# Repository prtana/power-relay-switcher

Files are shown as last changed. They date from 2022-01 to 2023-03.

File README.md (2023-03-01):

# Power Relay Switcher

**Power Relay Switcher** is an electronic device consisting of **4 relays**, each of which is capable of switching loads of up to **20 A**, **240 V AC** or **28 V DC**. Each of the four relays can be **manually** closed/opened from the **front panel** or via **USB** using **SCPI** commands. 

The device was designed for the automation of running battery pack management unit learning cycles for batteries up to a capacity of 200 Ah. In that application it is to be used in conjunction with a power supply, an electronic load and a multimeter. These battery learning cycles require charging-resting-discharging-resting periods in excess of 24 hours which are cumbersome for an operator to manually manage having to connect and disconnect a power supply and an electronic load at the exact moments determined by the learning cycle.

Power Relay Switcher

## User's Guide

### Front Panel
On the front panel there is a main **ON-OFF** rocker switch and **two toggle switches: USB/Manual** and **Close/Open** together with **two status LEDs** per relay. 

Front Panel

#### USB/Manual Switch
The **USB/Manual** switch allows the operator to choose whether the relay ought to be operated via **USB** using **SCPI** commands or **manually**. 

- If the **USB/Manual** switch is at the **USB** position, the **Close/Open** switch is disabled. 
- If the **USB/Manual** switch is switched from **USB** to **Manual**, the relay will be set to the position determined by the **Close/Open** switch. 
- If the **USB/Manual** switch is switched from **Manual** to **USB**, the relay will remain in the position last set by the **Close/Open** switch until a new **SCPI** command is sent to close or open it.

#### Close/Open Switch
The **Close/Open** switch allows the operator to manually close and open the relay contacts if the **USB/Manual** switch is at the **Manual** position. 

#### Status LEDs
There are two status LEDs per relay which indicate whether the relay contacts are in the **Closed** or **Open** position. 

### Rear Panel
On the rear panel there are:
- **USB Type-B** socket for SCPI control
- **Terminal blocks** with plugs for connecting to the relays' **Normally Open** (NO) and **Common** (COM) pins
- **Cooling fan**
- **230 V AC** mains C14 socket

Rear Panel

### SCPI
The following SCPI commands are supported:

- `*IDN?\n`
- `ROUTe:CLOSe (<channel list>)\n`
- `ROUTe:CLOSe? (<channel list>)\n`
- `ROUTe:OPEN (<channel list>)\n`
- `ROUTe:OPEN? (<channel list>)\n`

`<channel list>` is a list of relay channels to be switched or queried. It can be a single channel, i.e `2`, a comma seperated list, i.e `2,4` or a range, i.e `1:3`.

#### \*IDN?\n
- Device identification query.
- Returns the vendor, model, serial number and firmware version in comma seperated format.
- Example `*IDN?\n` returns `Deeply Embedded,Power Relay Switcher,0,0\n`.

#### ROUTe:CLOSe (\<channel list\>)\n
- Closes the relays specified by the `<channel list\>`.
- The relay's **USB/Manual** switch has to be set to **USB** in order to switch it using SCPI.
- Returns nothing.
- Example to close relays one and four: `ROUT:CLOS (1,4)\n`

#### ROUTe:CLOSe? (\<channel list\>)\n
- Queries whether the relays specified by the `<channel list\>` are closed.
- Returns the status of queried relays in a comma seperated form, where 1 - closed, 0 - open.
- Example to query relays one to four: `ROUT:CLOS? (1:4)\n`; returns in case if relay one is closed and two to four are open: `1,0,0,0\n`.

#### ROUTe:OPEN (\<channel list\>)\n
- Opens the relays specified by the `<channel list\>`. 
- The relay's **USB/Manual** switch has to be set to **USB** in order to switch it using SCPI.
- Returns nothing.
- Example to open relays one to three: `ROUT:OPEN (1:3)\n`.

#### ROUTe:OPEN? (\<channel list\>)\n
- Queries whether the relays specified by the `<channel list\>` are open.
- Returns the status of queried relays in a comma seperated form, where 1 - open, 0 - closed.
- Example to query relays one to four: `ROUT:OPEN? (1:4)\n`; returns in case if relay one is closed and two to four are open: `0,1,1,1\n`.

#### Usage Example
- Determine the COM port in use.
- Use your preferred terminal program. In this case **PUTTY** is used, the COM port is `/dev/ttyACM1` and baudrate is selected `115200`. 

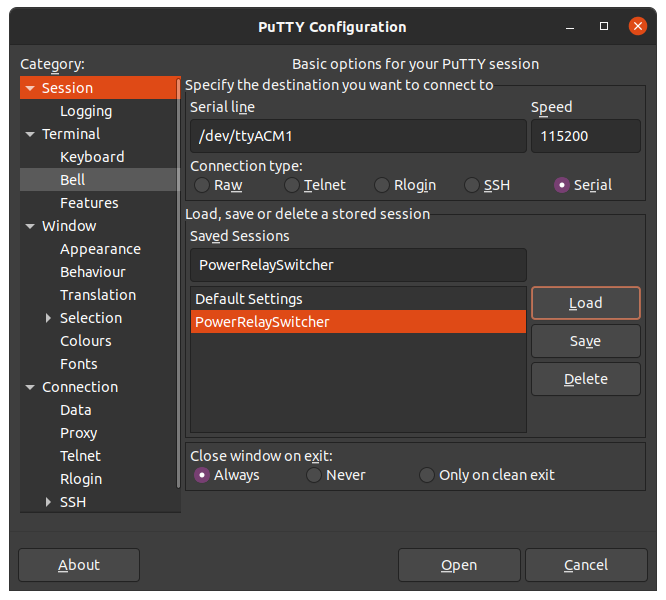
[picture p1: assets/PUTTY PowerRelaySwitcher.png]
PUTTY Configuration

- For PUTTY, make sure to select `Force on` for `Local echo` and `Local line editing` to see the typed text and to send the whole line at once rather than character by character.

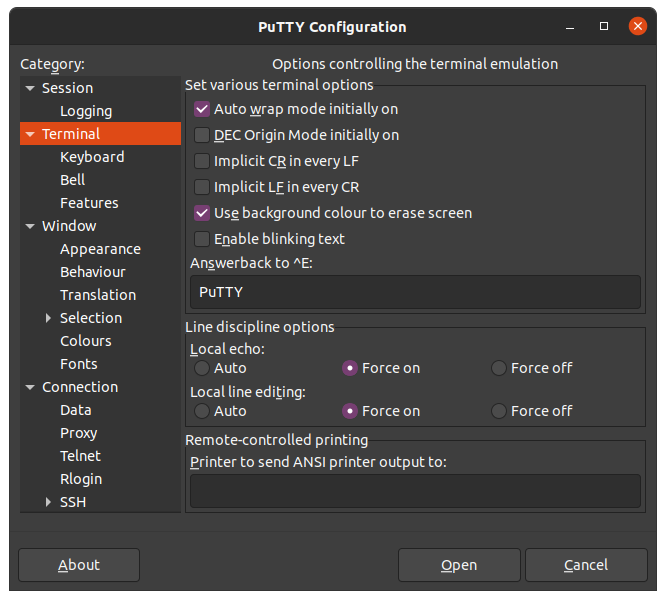
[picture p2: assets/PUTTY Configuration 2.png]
PUTTY Configuration


- Example comminucation is as follows. Note that a newline character `\n` can be entered in PUTTY by `Ctrl + J` and is displayed as `^J`.

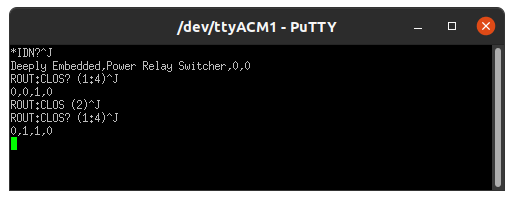
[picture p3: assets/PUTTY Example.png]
PUTTY Example Communication


## Project Overview

### Firmware
The C code for the STM32L062K8Tx microcontroller is in the [/firmware/power-relay-switcher](https://github.com/prtana/power-relay-switcher/tree/main/firmware/power-relay-switcher) directory.

### Hardware
There are relevant files in the [/hardware](https://github.com/prtana/power-relay-switcher/tree/main/hardware) directory for the three PCBs: the main PCB and the aluminium front and back panels.

#### Main PCB
For the main PCB the following resources are available:
- [3D step model](https://github.com/prtana/power-relay-switcher/tree/main/hardware/PRS_relay_board/3D)
- [Bill of materials](https://github.com/prtana/power-relay-switcher/tree/main/hardware/PRS_relay_board/BOM)
- [KiCad project](https://github.com/prtana/power-relay-switcher/tree/main/hardware/PRS_relay_board/KiCad)
- [Gerber files](https://github.com/prtana/power-relay-switcher/tree/main/hardware/PRS_relay_board/Gerbers)
- [PDF schematic](https://github.com/prtana/power-relay-switcher/blob/main/hardware/PRS_relay_board/PRS_relay_board.pdf)

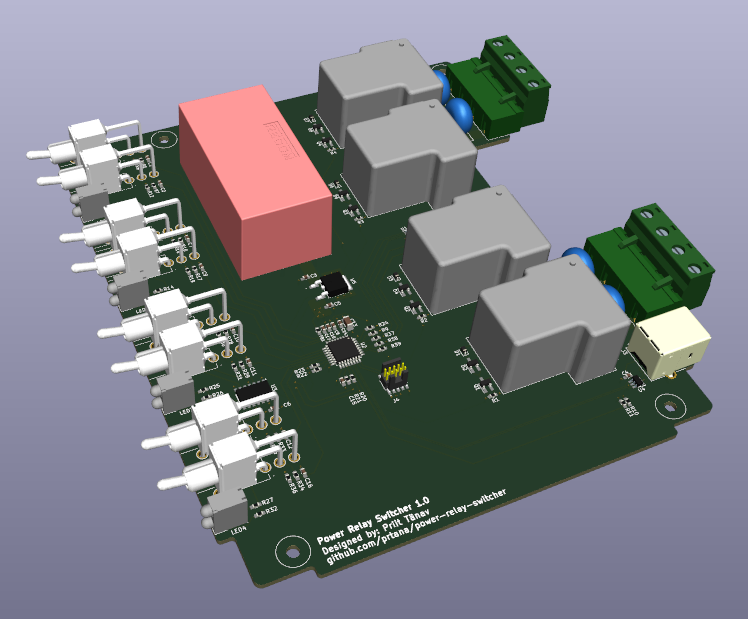
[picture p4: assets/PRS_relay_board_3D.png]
Relay Board


#### Front Panel
For the aluminium front panel the following resources are available:
- [3D step model](https://github.com/prtana/power-relay-switcher/tree/main/hardware/PRS_front_panel/3D)
- [KiCad project](https://github.com/prtana/power-relay-switcher/tree/main/hardware/PRS_front_panel/KiCad)
- [Gerber files](https://github.com/prtana/power-relay-switcher/tree/main/hardware/PRS_front_panel/Gerbers)

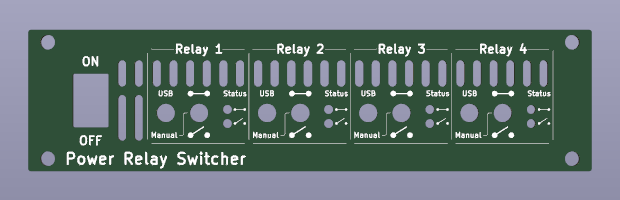
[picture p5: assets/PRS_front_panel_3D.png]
Front Panel


#### Rear Panel
For the aluminium rear panel the following resources are available:
- [3D step model](https://github.com/prtana/power-relay-switcher/tree/main/hardware/PRS_rear_panel/3D)
- [KiCad project](https://github.com/prtana/power-relay-switcher/tree/main/hardware/PRS_rear_panel/KiCad)
- [Gerber files](https://github.com/prtana/power-relay-switcher/tree/main/hardware/PRS_rear_panel/Gerbers)

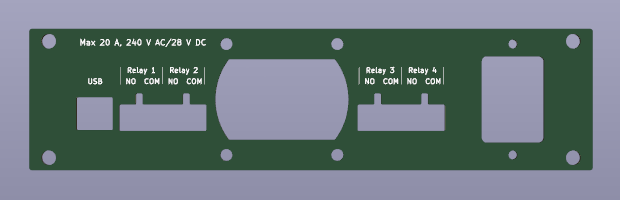
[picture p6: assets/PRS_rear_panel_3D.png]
Rear Panel


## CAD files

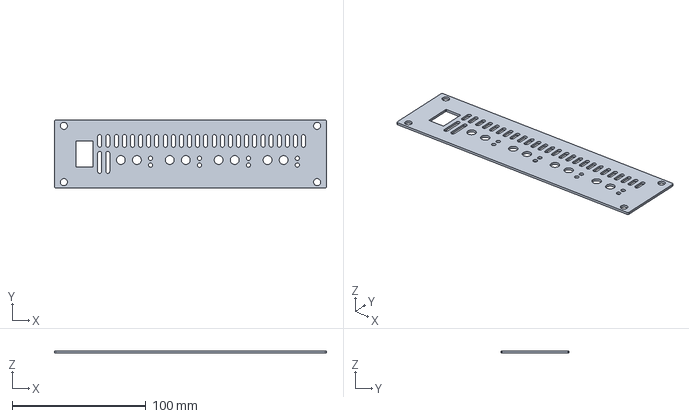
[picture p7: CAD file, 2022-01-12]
hardware/PRS_front_panel/3D/PRS_front_panel.step
203.0 x 51.0 x 1.60 mm

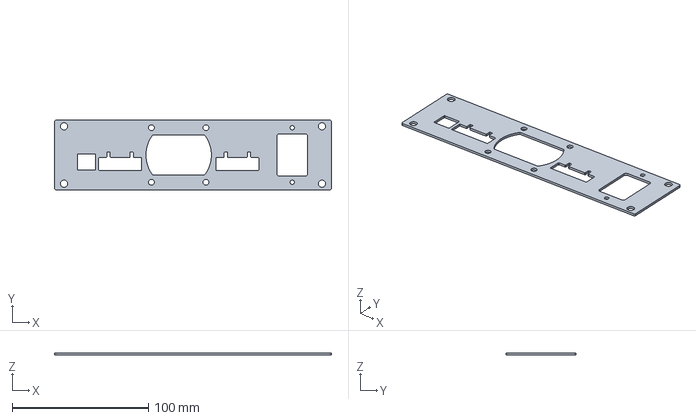
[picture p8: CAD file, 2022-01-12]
hardware/PRS_rear_panel/3D/PRS_rear_panel.step
203.0 x 51.0 x 1.60 mm

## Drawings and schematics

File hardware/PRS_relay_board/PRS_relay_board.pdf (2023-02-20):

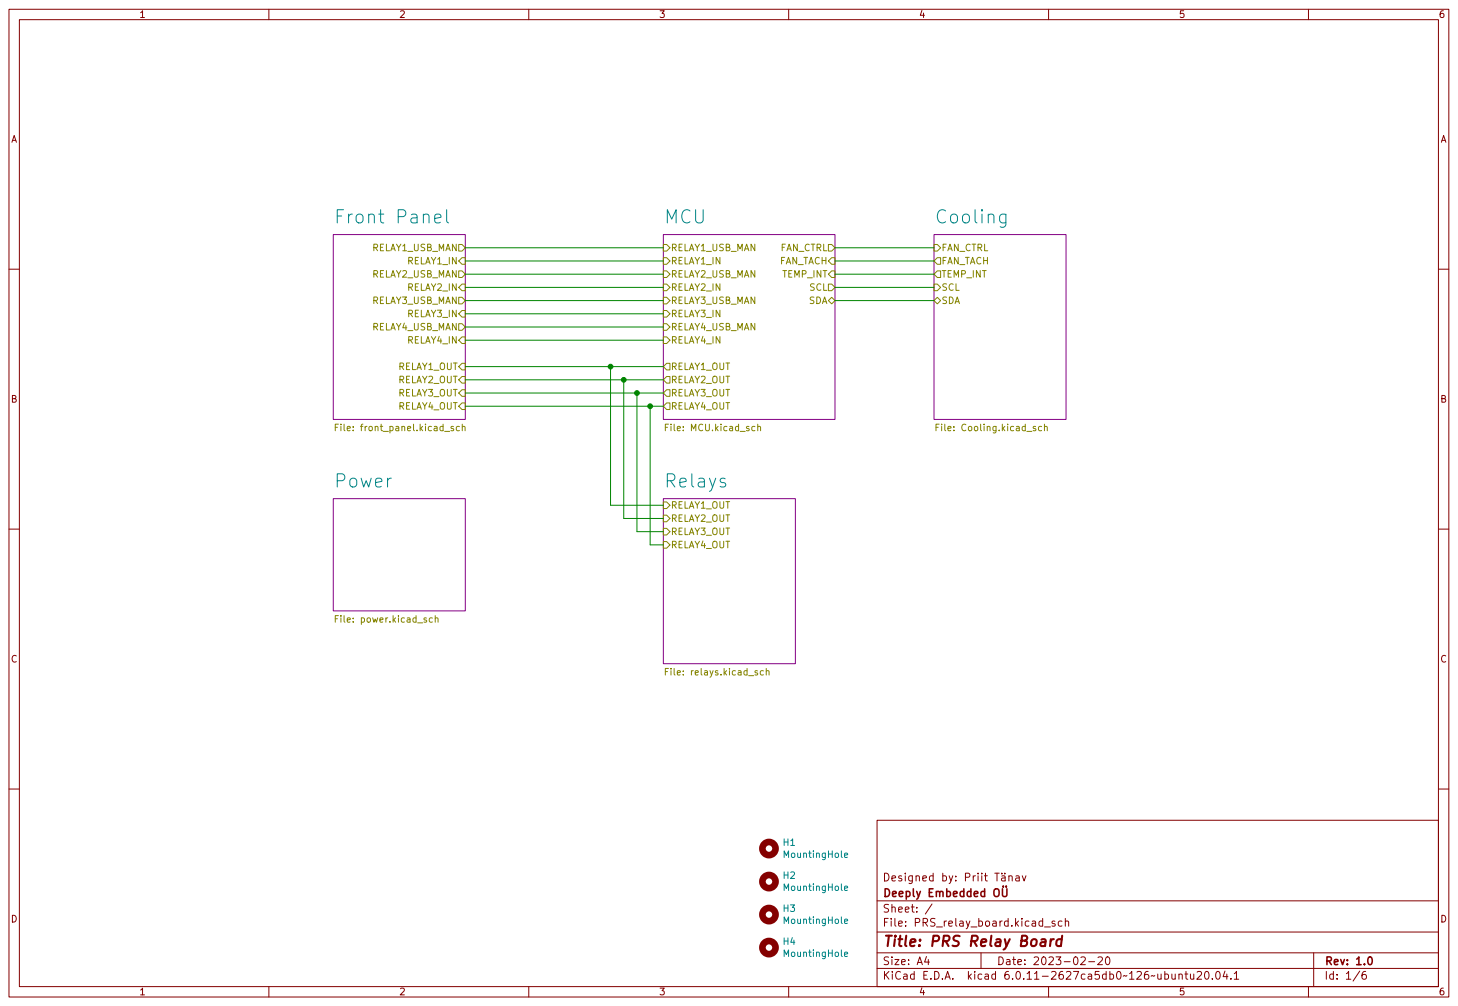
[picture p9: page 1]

File: power.kicad_sch RELAY1_USB_MAN
File: Cooling.kicad_sch H4 MountingHole H3 MountingHole H2 MountingHole H1 MountingHole

Id: 1/6 Title: PRS Relay Board

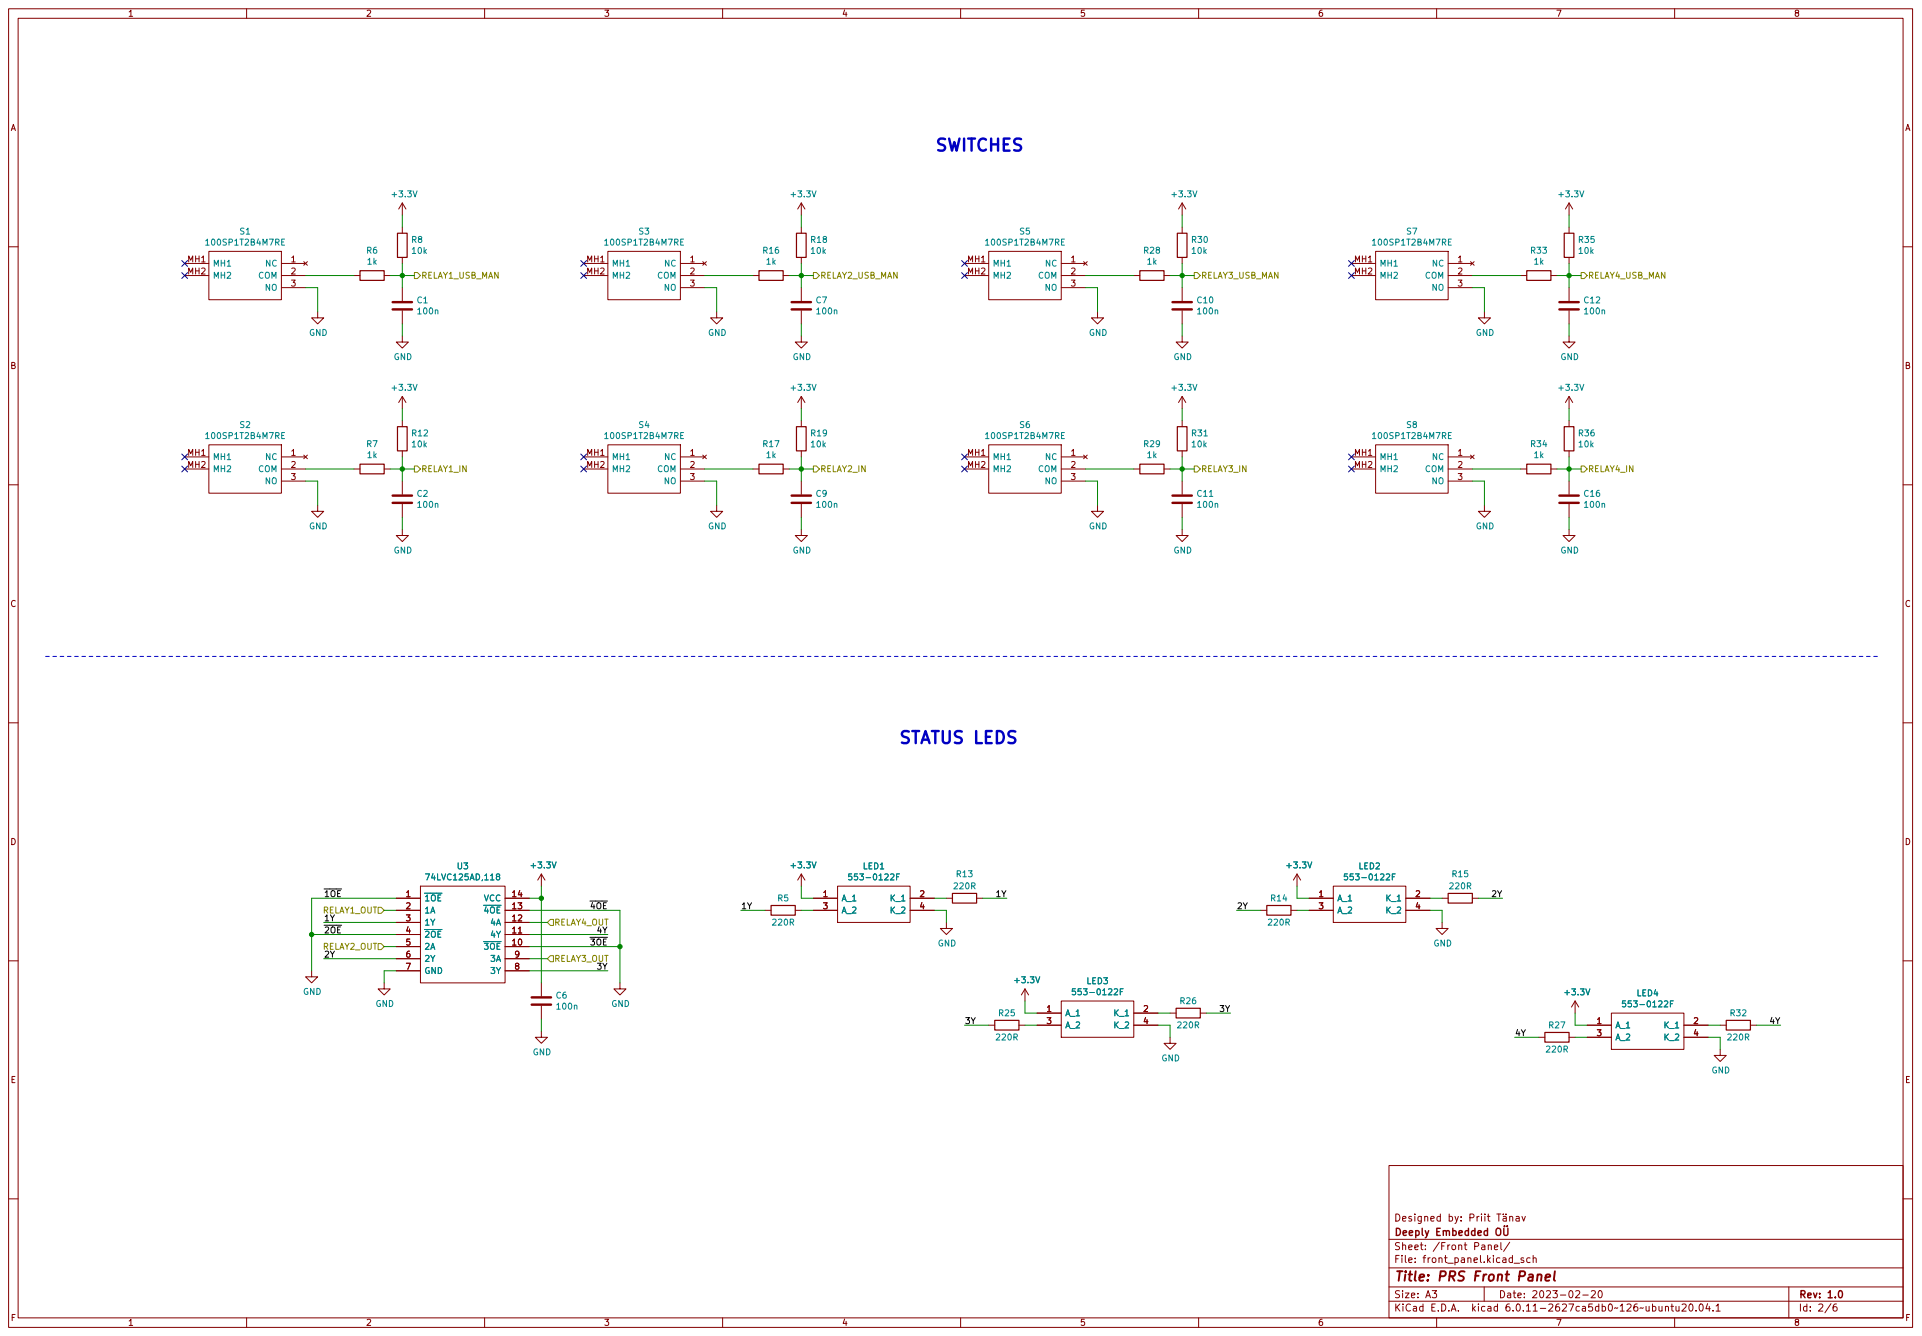
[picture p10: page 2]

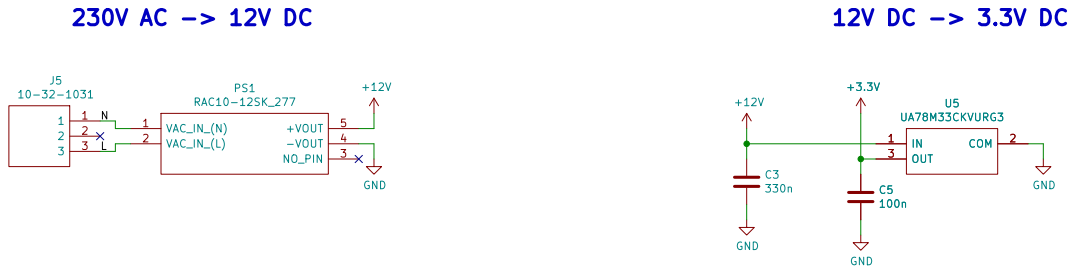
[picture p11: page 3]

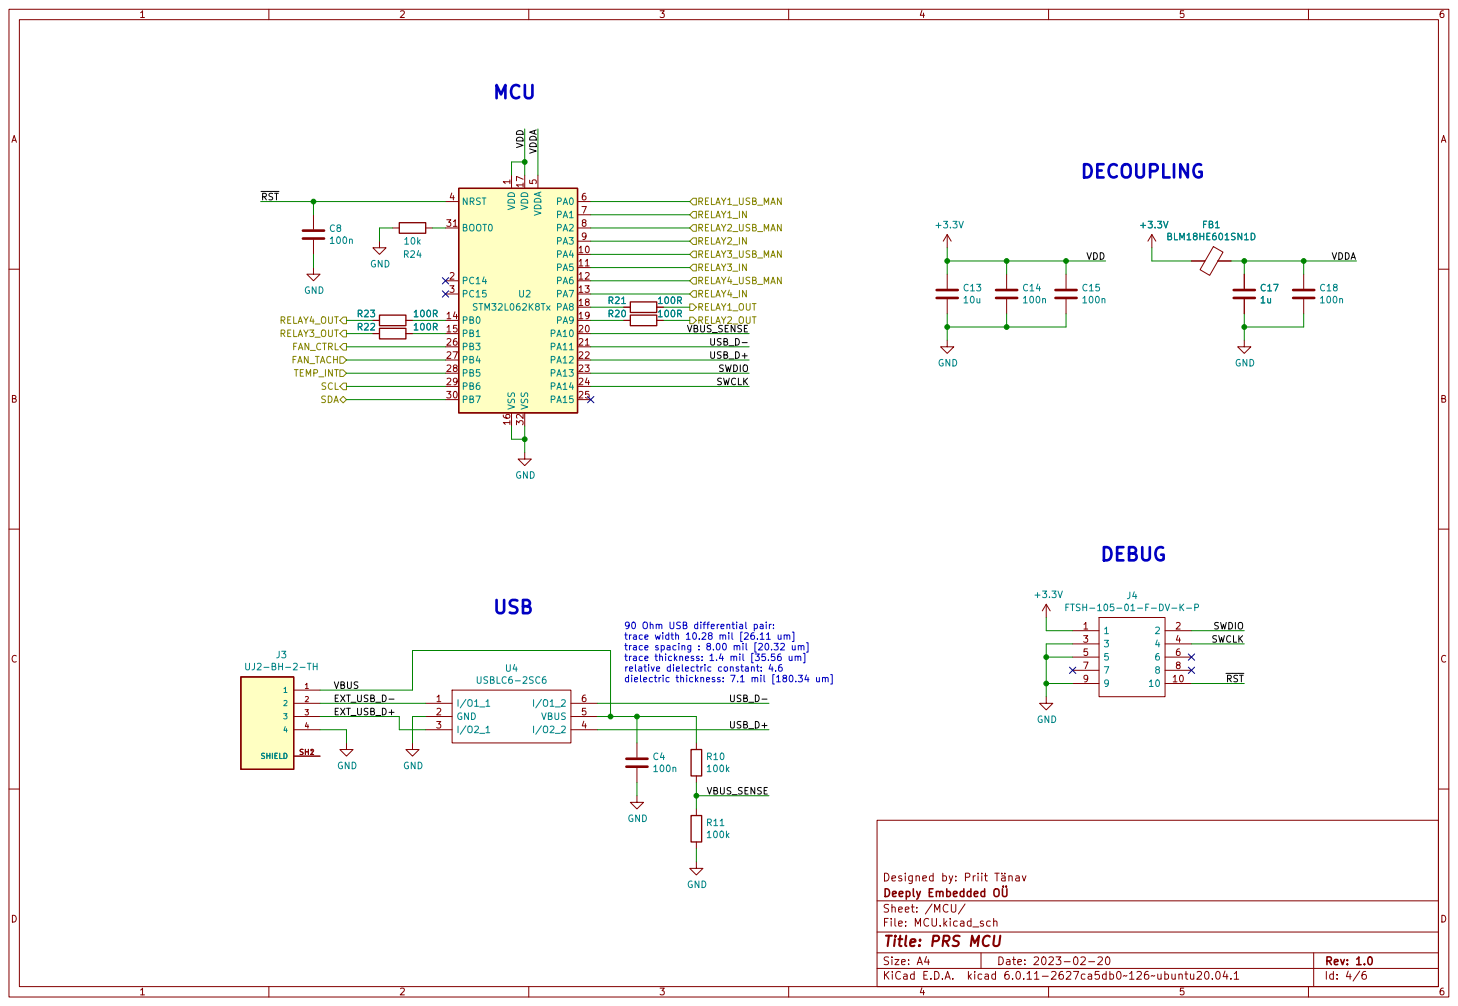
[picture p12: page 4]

Id: 4/6 Title: PRS MCU

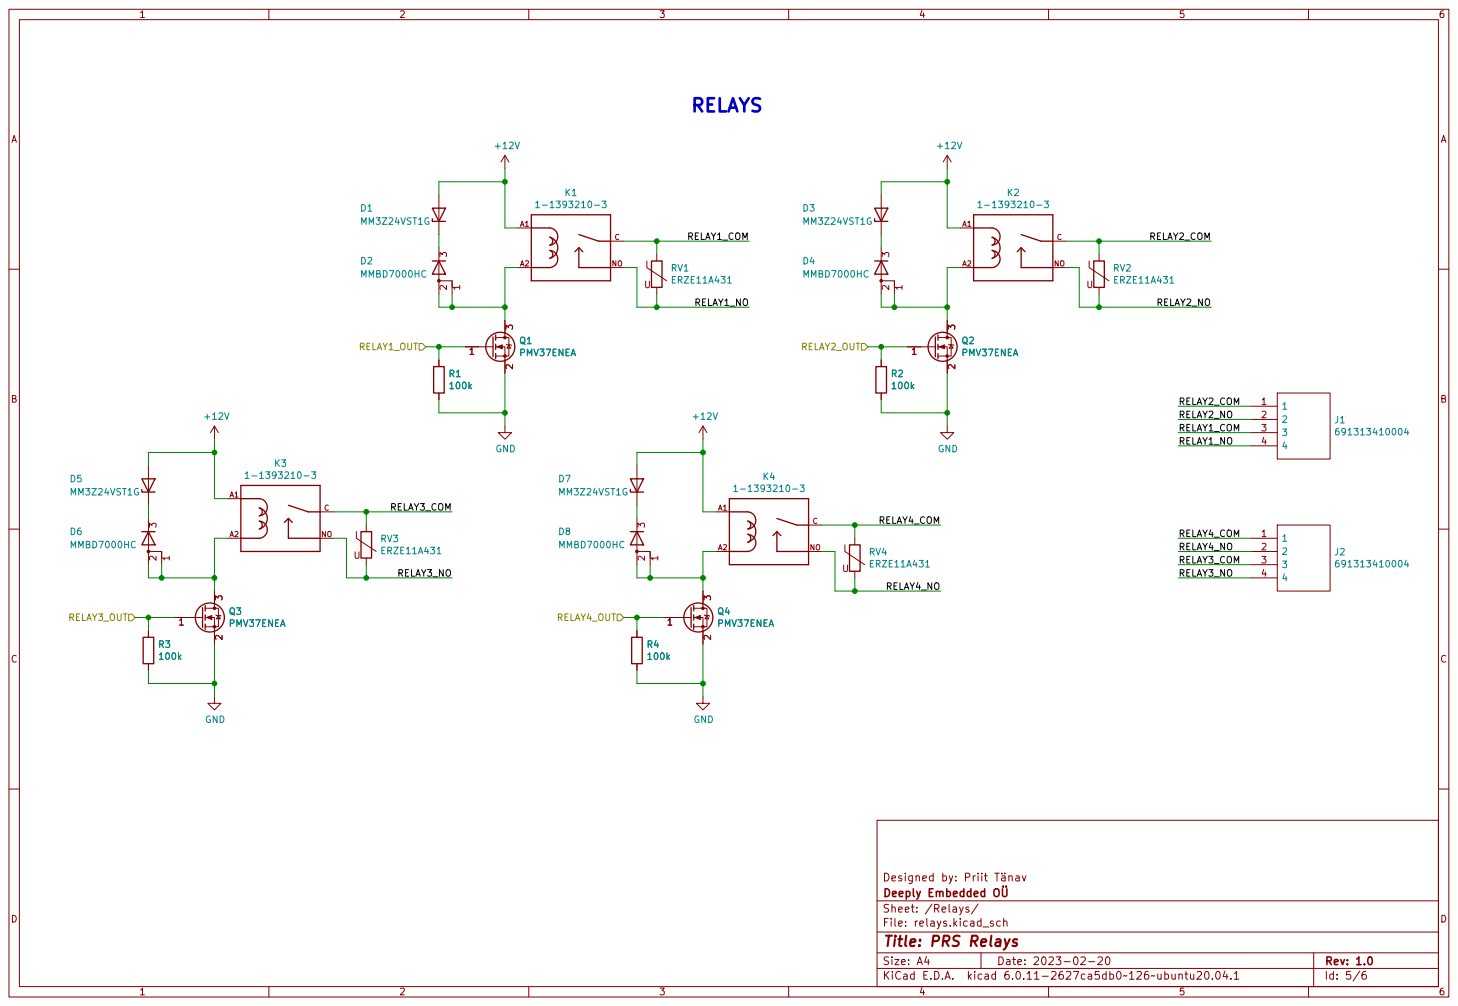
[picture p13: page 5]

File: relays.kicad_sch Sheet: /Relays/
Id: 5/6 Title: PRS Relays

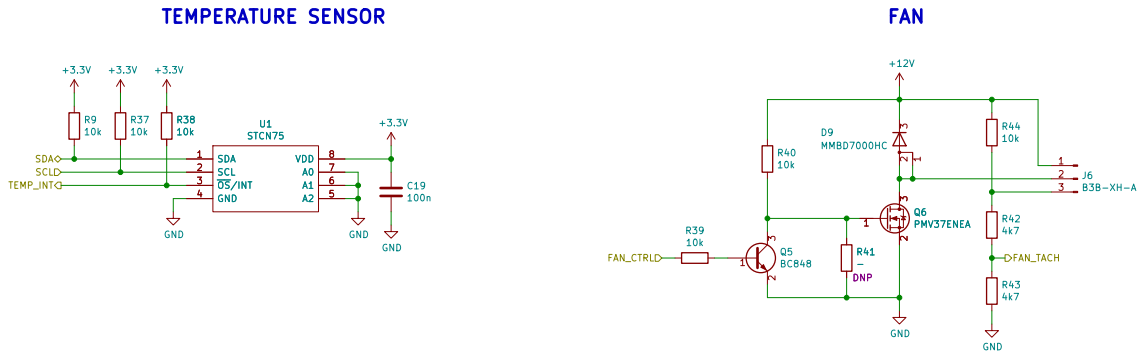
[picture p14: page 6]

File: Cooling.kicad_sch Sheet: /Cooling/
Id: 6/6 Title: PRS Cooling

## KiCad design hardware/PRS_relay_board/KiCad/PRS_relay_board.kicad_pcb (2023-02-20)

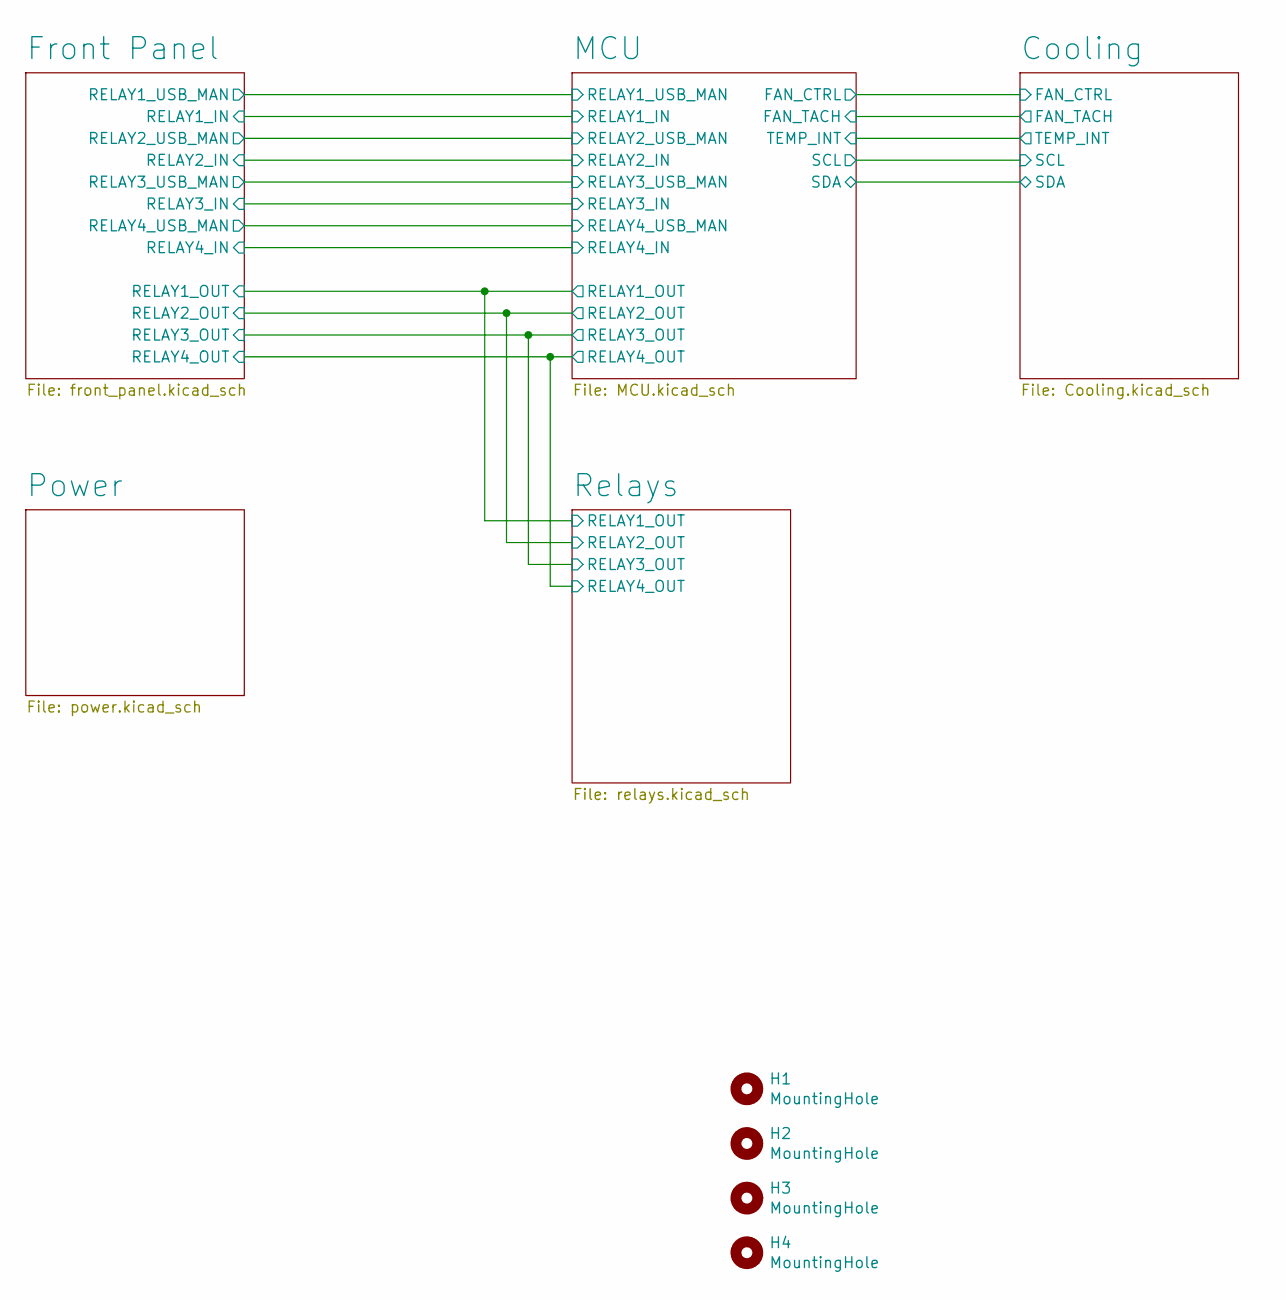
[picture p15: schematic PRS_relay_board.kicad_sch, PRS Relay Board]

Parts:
H1, H2, H3, H4: MountingHole; MountingHole_3.2mm_M3_DIN965

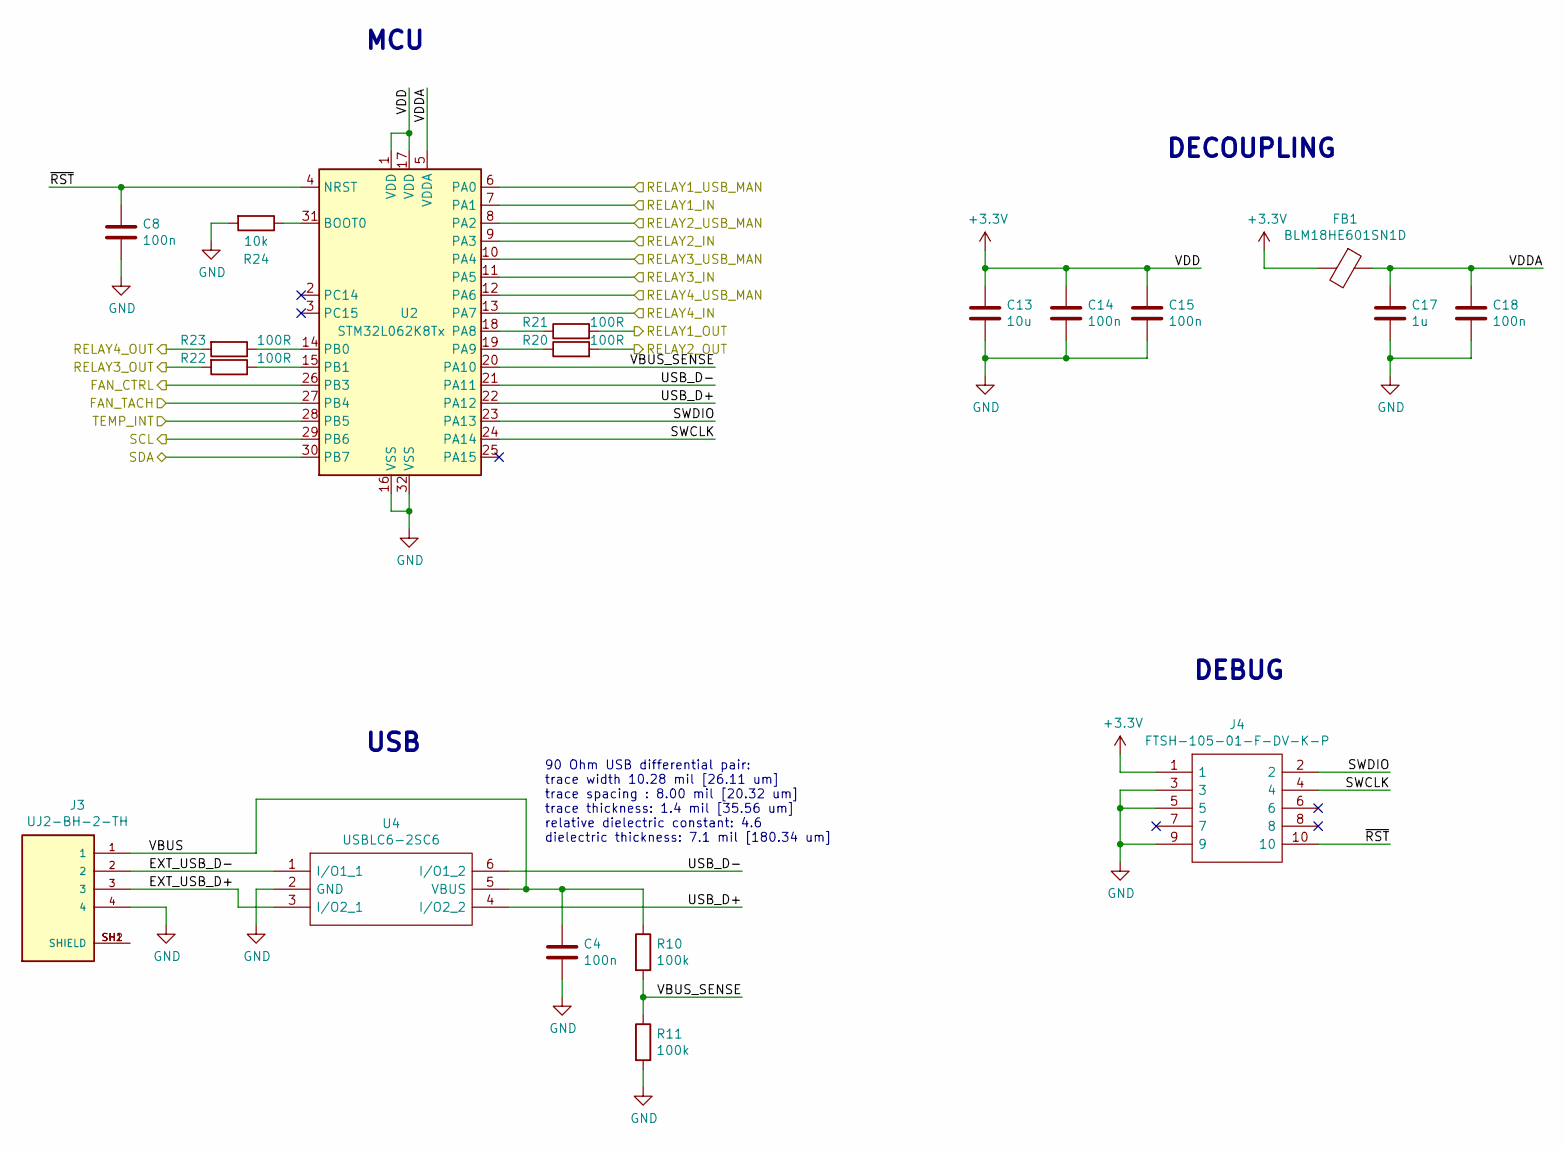
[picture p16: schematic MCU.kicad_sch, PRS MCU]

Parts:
C4, C8, C14, C15, C18: 100n; C_0603_1608Metric_Pad1.08x0.95mm_HandSolder
C13: 10u; C_1206_3216Metric_Pad1.33x1.80mm_HandSolder
C17: 1u; C_0603_1608Metric_Pad1.08x0.95mm_HandSolder
FB1: BLM18HE601SN1D; R_0603_1608Metric_Pad0.98x0.95mm_HandSolder
J3: UJ2-BH-2-TH; CUI_UJ2-BH-2-TH; PART_REV 1.0
J4: FTSH-105-01-F-DV-K-P; FTSH-105-XX-YYY-DV-K-P; Manufacturer_Part_Number FTSH-105-01-F-DV-K-P; Mouser Part Number 200-FTSH10501FDVKP
R10, R11: 100k; R_0603_1608Metric_Pad0.98x0.95mm_HandSolder
R20, R21, R22, R23: 100R; R_0603_1608Metric_Pad0.98x0.95mm_HandSolder
R24: 10k; R_0603_1608Metric_Pad0.98x0.95mm_HandSolder
U2: STM32L062K8Tx; LQFP-32_7x7mm_P0.8mm
U4: USBLC6-2SC6; SOT95P280X145-6N; Manufacturer_Part_Number USBLC6-2SC6; Mouser Part Number 511-USBLC6-2SC6

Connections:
+3V3: C13.1, C14.1, C15.1, FB1.2, J4.1, U2.1 (VDD), U2.17 (VDD); also elsewhere on the board
/Cooling/FAN_CTRL: U2.26 (PB3); also elsewhere on the board
/Cooling/FAN_TACH: U2.27 (PB4); also elsewhere on the board
/Cooling/SCL: U2.29 (PB6); also elsewhere on the board
/Cooling/SDA: U2.30 (PB7); also elsewhere on the board
/Cooling/TEMP_INT: U2.28 (PB5); also elsewhere on the board
/Front Panel/RELAY1_IN: U2.7 (PA1); also elsewhere on the board
/Front Panel/RELAY1_OUT: R21.2; also elsewhere on the board
/Front Panel/RELAY1_USB_MAN: U2.6 (PA0); also elsewhere on the board
/Front Panel/RELAY2_IN: U2.9 (PA3); also elsewhere on the board
/Front Panel/RELAY2_OUT: R20.2; also elsewhere on the board
/Front Panel/RELAY2_USB_MAN: U2.8 (PA2); also elsewhere on the board
/Front Panel/RELAY3_IN: U2.11 (PA5); also elsewhere on the board
/Front Panel/RELAY3_OUT: R22.2; also elsewhere on the board
/Front Panel/RELAY3_USB_MAN: U2.10 (PA4); also elsewhere on the board
/Front Panel/RELAY4_IN: U2.13 (PA7); also elsewhere on the board
/Front Panel/RELAY4_OUT: R23.2; also elsewhere on the board
/Front Panel/RELAY4_USB_MAN: U2.12 (PA6); also elsewhere on the board
/MCU/EXT_USB_D+: J3.3, U4.3 (I/O2_1)
/MCU/EXT_USB_D-: J3.2, U4.1 (I/O1_1)
/MCU/SWCLK: J4.4, U2.24 (PA14)
/MCU/SWDIO: J4.2, U2.23 (PA13)
/MCU/USB_D+: U2.22 (PA12), U4.4 (I/O2_2)
/MCU/USB_D-: U2.21 (PA11), U4.6 (I/O1_2)
/MCU/VBUS: C4.1, J3.1, R10.1, U4.5 (VBUS)
/MCU/VBUS_SENSE: R10.2, R11.1, U2.20 (PA10)
/MCU/VDDA: C17.1, C18.1, FB1.1, U2.5 (VDDA)
/MCU/~RST: C8.1, J4.10, U2.4 (NRST)
GND: C4.2, C8.2, C13.2, C14.2, C15.2, C17.2, C18.2, J3.4, J4.3, J4.5, J4.9, R11.2, R24.2, U2.16 (VSS), U2.32 (VSS), U4.2 (GND); also elsewhere on the board
unnamed: J3.SH1 (SHIELD), J3.SH2 (SHIELD)
unnamed: R20.1, U2.19 (PA9)
unnamed: R21.1, U2.18 (PA8)
unnamed: R22.1, U2.15 (PB1)
unnamed: R23.1, U2.14 (PB0)
unnamed: R24.1, U2.31 (BOOT0)

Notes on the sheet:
DEBUG
90 Ohm USB differential pair: trace width 10.28 mil [26.11 um] trace spacing : 8.00 mil [20.32 um] trace thickness: 1.4 mil [35.56 um] relative dielectric constant: 4.6 dielectric thickness: 7.1 mil [180.34 um]
USB
MCU
DECOUPLING

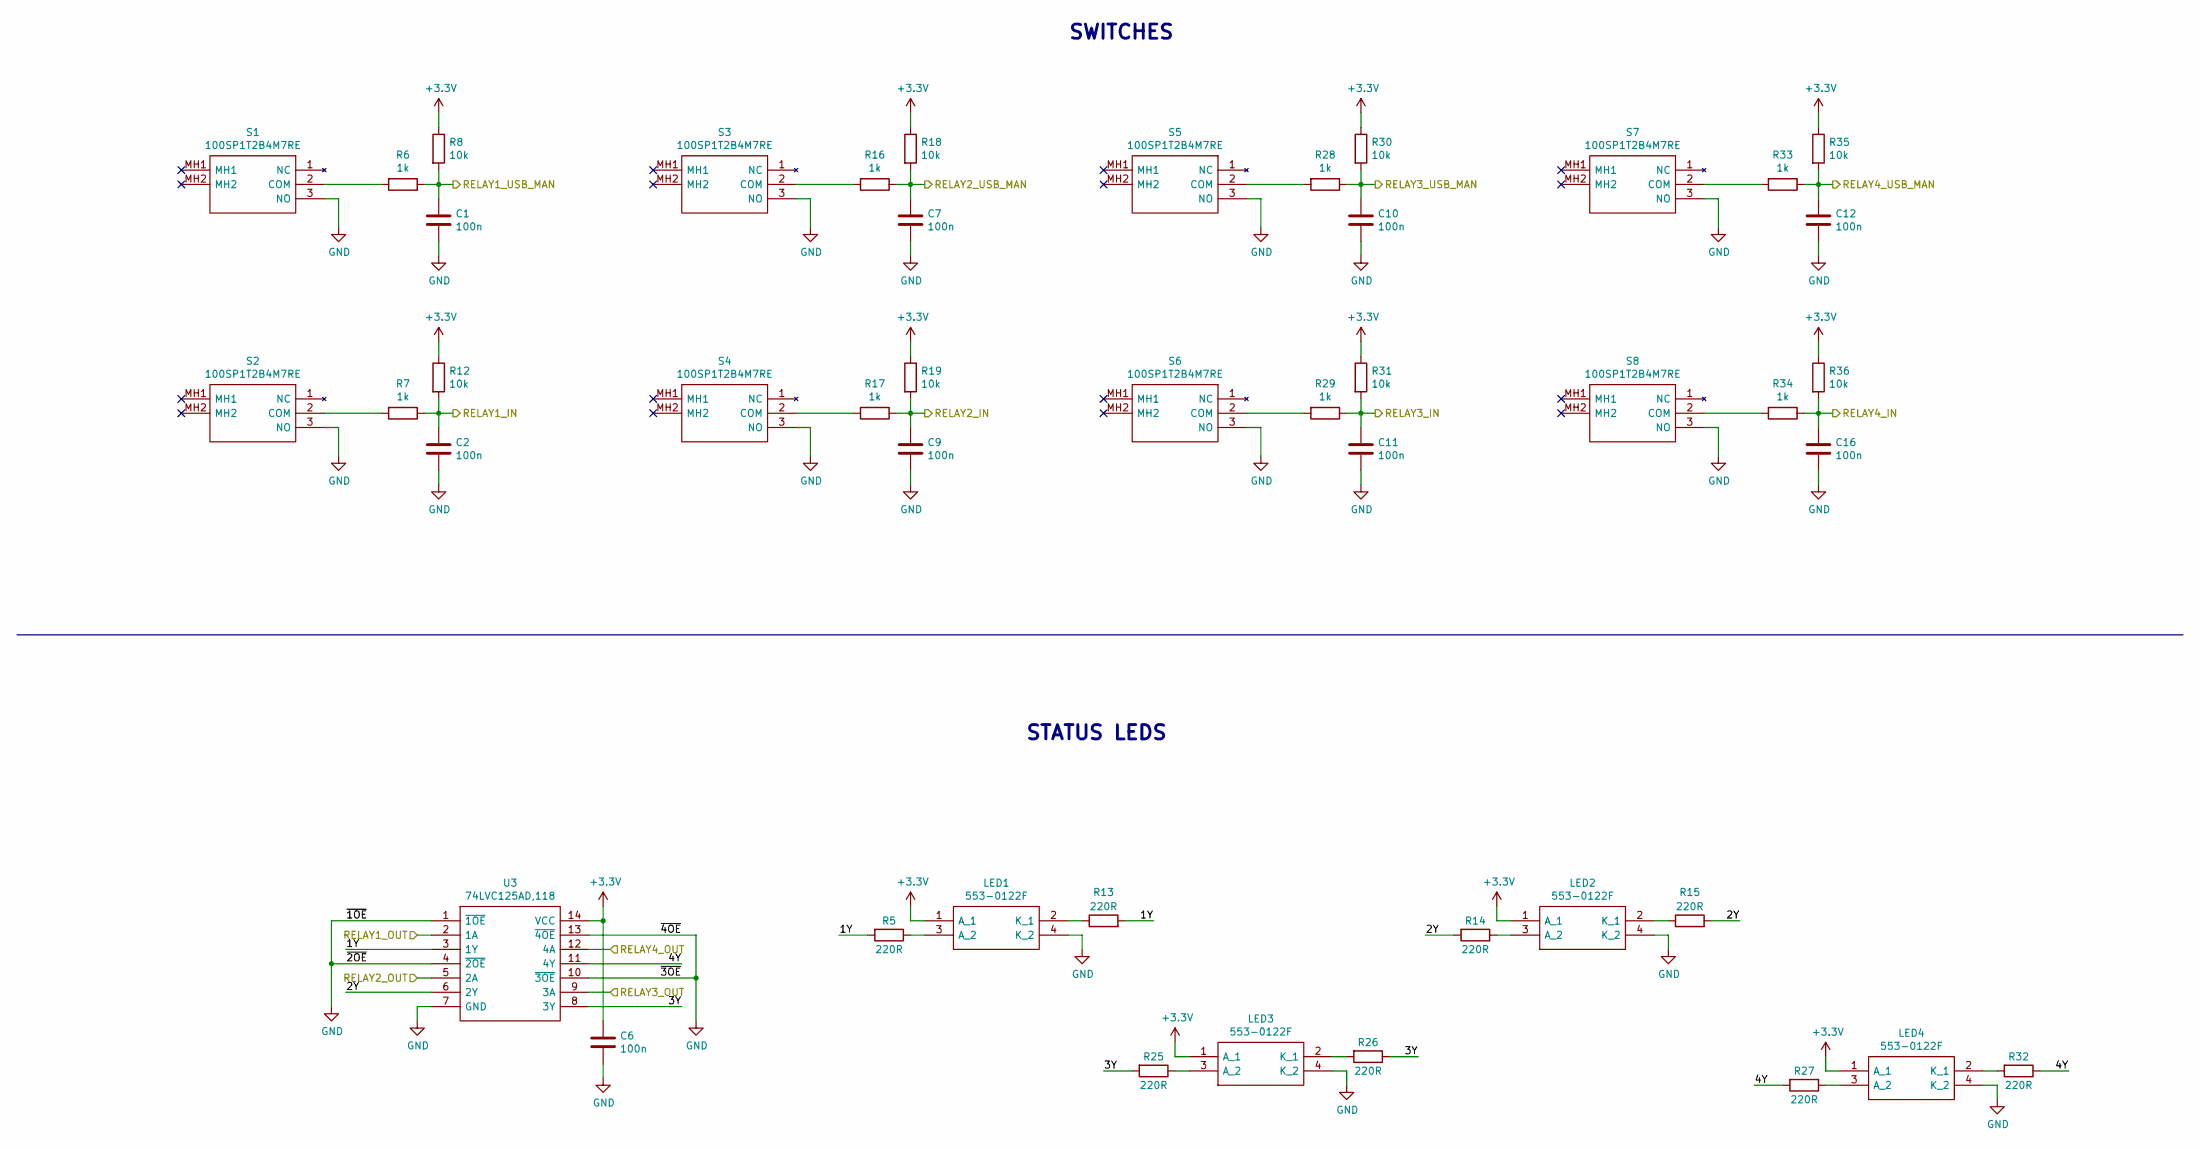
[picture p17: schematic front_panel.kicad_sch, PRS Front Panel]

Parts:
C1, C2, C6, C7, C9, C10, C11, C12, C16: 100n; C_0603_1608Metric_Pad1.08x0.95mm_HandSolder
LED1, LED2, LED3, LED4: 553-0122F; 5530122F; Manufacturer_Part_Number 553-0122F; Mouser Part Number 645-553-0122F
R5, R13, R14, R15, R25, R26, R27, R32: 220R; R_0603_1608Metric_Pad0.98x0.95mm_HandSolder
R6, R7, R16, R17, R28, R29, R33, R34: 1k; R_0603_1608Metric_Pad0.98x0.95mm_HandSolder
R8, R12, R18, R19, R30, R31, R35, R36: 10k; R_0603_1608Metric_Pad0.98x0.95mm_HandSolder
S1, S2, S3, S4, S5, S6, S7, S8: 100SP1T2B4M7RE; Manufacturer_Part_Number 100SP1T2B4M7RE; Mouser Part Number 612-100-A2472
U3: 74LVC125AD,118; SOIC127P600X175-14N; Manufacturer_Part_Number 74LVC125AD,118; Mouser Part Number 771-74LVC125AD-T

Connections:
+3V3: C6.1, LED1.1 (A_1), LED2.1 (A_1), LED3.1 (A_1), LED4.1 (A_1), R8.1, R12.1, R18.1, R19.1, R30.1, R31.1, R35.1, R36.1, U3.14 (VCC); also elsewhere on the board
/Front Panel/1Y: R5.2, R13.2, U3.3 (1Y)
/Front Panel/2Y: R14.2, R15.2, U3.6 (2Y)
/Front Panel/3Y: R25.2, R26.1, U3.8 (3Y)
/Front Panel/4Y: R27.2, R32.1, U3.11 (4Y)
/Front Panel/RELAY1_IN: C2.1, R7.1, R12.2; also elsewhere on the board
/Front Panel/RELAY1_OUT: U3.2 (1A); also elsewhere on the board
/Front Panel/RELAY1_USB_MAN: C1.1, R6.1, R8.2; also elsewhere on the board
/Front Panel/RELAY2_IN: C9.1, R17.1, R19.2; also elsewhere on the board
/Front Panel/RELAY2_OUT: U3.5 (2A); also elsewhere on the board
/Front Panel/RELAY2_USB_MAN: C7.1, R16.1, R18.2; also elsewhere on the board
/Front Panel/RELAY3_IN: C11.1, R29.1, R31.2; also elsewhere on the board
/Front Panel/RELAY3_OUT: U3.9 (3A); also elsewhere on the board
/Front Panel/RELAY3_USB_MAN: C10.1, R28.1, R30.2; also elsewhere on the board
/Front Panel/RELAY4_IN: C16.1, R34.1, R36.2; also elsewhere on the board
/Front Panel/RELAY4_OUT: U3.12 (4A); also elsewhere on the board
/Front Panel/RELAY4_USB_MAN: C12.1, R33.1, R35.2; also elsewhere on the board
GND: C1.2, C2.2, C6.2, C7.2, C9.2, C10.2, C11.2, C12.2, C16.2, LED1.4 (K_2), LED2.4 (K_2), LED3.4 (K_2), LED4.4 (K_2), S1.3 (NO), S2.3 (NO), S3.3 (NO), S4.3 (NO), S5.3 (NO), S6.3 (NO), S7.3 (NO), S8.3 (NO), U3.1 (~1OE), U3.4 (~2OE), U3.7 (GND), U3.10 (~3OE), U3.13 (~4OE); also elsewhere on the board
unnamed: LED1.2 (K_1), R13.1
unnamed: LED1.3 (A_2), R5.1
unnamed: LED2.2 (K_1), R15.1
unnamed: LED2.3 (A_2), R14.1
unnamed: LED3.2 (K_1), R26.2
unnamed: LED3.3 (A_2), R25.1
unnamed: LED4.2 (K_1), R32.2
unnamed: LED4.3 (A_2), R27.1
unnamed: R6.2, S1.2 (COM)
unnamed: R7.2, S2.2 (COM)
unnamed: R16.2, S3.2 (COM)
unnamed: R17.2, S4.2 (COM)
unnamed: R28.2, S5.2 (COM)
unnamed: R29.2, S6.2 (COM)
unnamed: R33.2, S7.2 (COM)
unnamed: R34.2, S8.2 (COM)

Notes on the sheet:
STATUS LEDS
SWITCHES

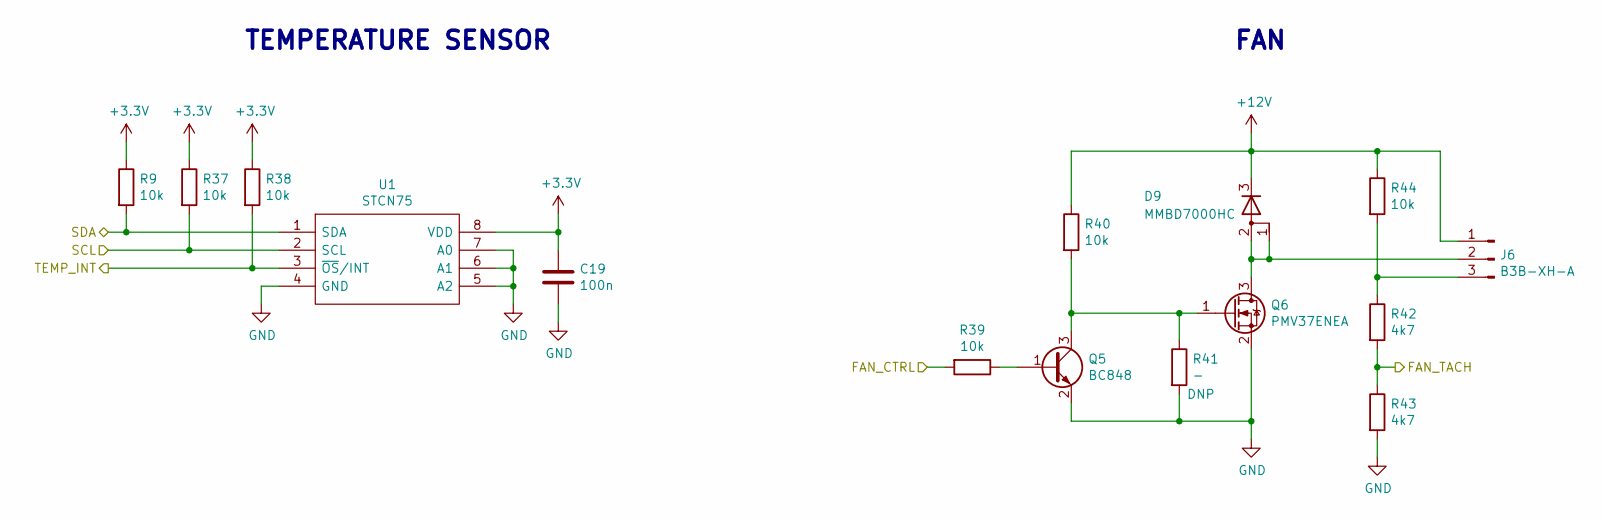
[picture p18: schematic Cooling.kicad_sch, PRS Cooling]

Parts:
C19: 100n; C_0603_1608Metric_Pad1.08x0.95mm_HandSolder
D9: MMBD7000HC; SOT-23_Handsoldering
J6: B3B-XH-A; JST_XH_B3B-XH-A_1x03_P2.50mm_Vertical
Q5: BC848; SOT-23_Handsoldering
Q6: PMV37ENEA; SOT-23_Handsoldering
R9, R37, R38, R39, R40, R44: 10k; R_0603_1608Metric_Pad0.98x0.95mm_HandSolder
R41: -; R_0603_1608Metric_Pad0.98x0.95mm_HandSolder
R42, R43: 4k7; R_0603_1608Metric_Pad0.98x0.95mm_HandSolder
U1: STCN75; SOP65P490X110-8N; Manufacturer_Part_Number STCN75

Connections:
+3V3: C19.1, R9.1, R37.1, R38.1, U1.8 (VDD); also elsewhere on the board
+12V: D9.3 (K), J6.1, R40.1, R44.1; also elsewhere on the board
/Cooling/FAN_CTRL: R39.2; also elsewhere on the board
/Cooling/FAN_TACH: R42.2, R43.1; also elsewhere on the board
/Cooling/SCL: R37.2, U1.2 (SCL); also elsewhere on the board
/Cooling/SDA: R9.2, U1.1 (SDA); also elsewhere on the board
/Cooling/TEMP_INT: R38.2, U1.3 (~OS/INT); also elsewhere on the board
GND: C19.2, Q5.2 (E), Q6.2 (S), R41.2, R43.2, U1.4 (GND), U1.5 (A2), U1.6 (A1), U1.7 (A0); also elsewhere on the board
unnamed: D9.1 (A), D9.2 (A), J6.2, Q6.3 (D)
unnamed: J6.3, R42.1, R44.2
unnamed: Q5.1 (B), R39.1
unnamed: Q5.3 (C), Q6.1 (G), R40.2, R41.1

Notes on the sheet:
FAN
TEMPERATURE SENSOR

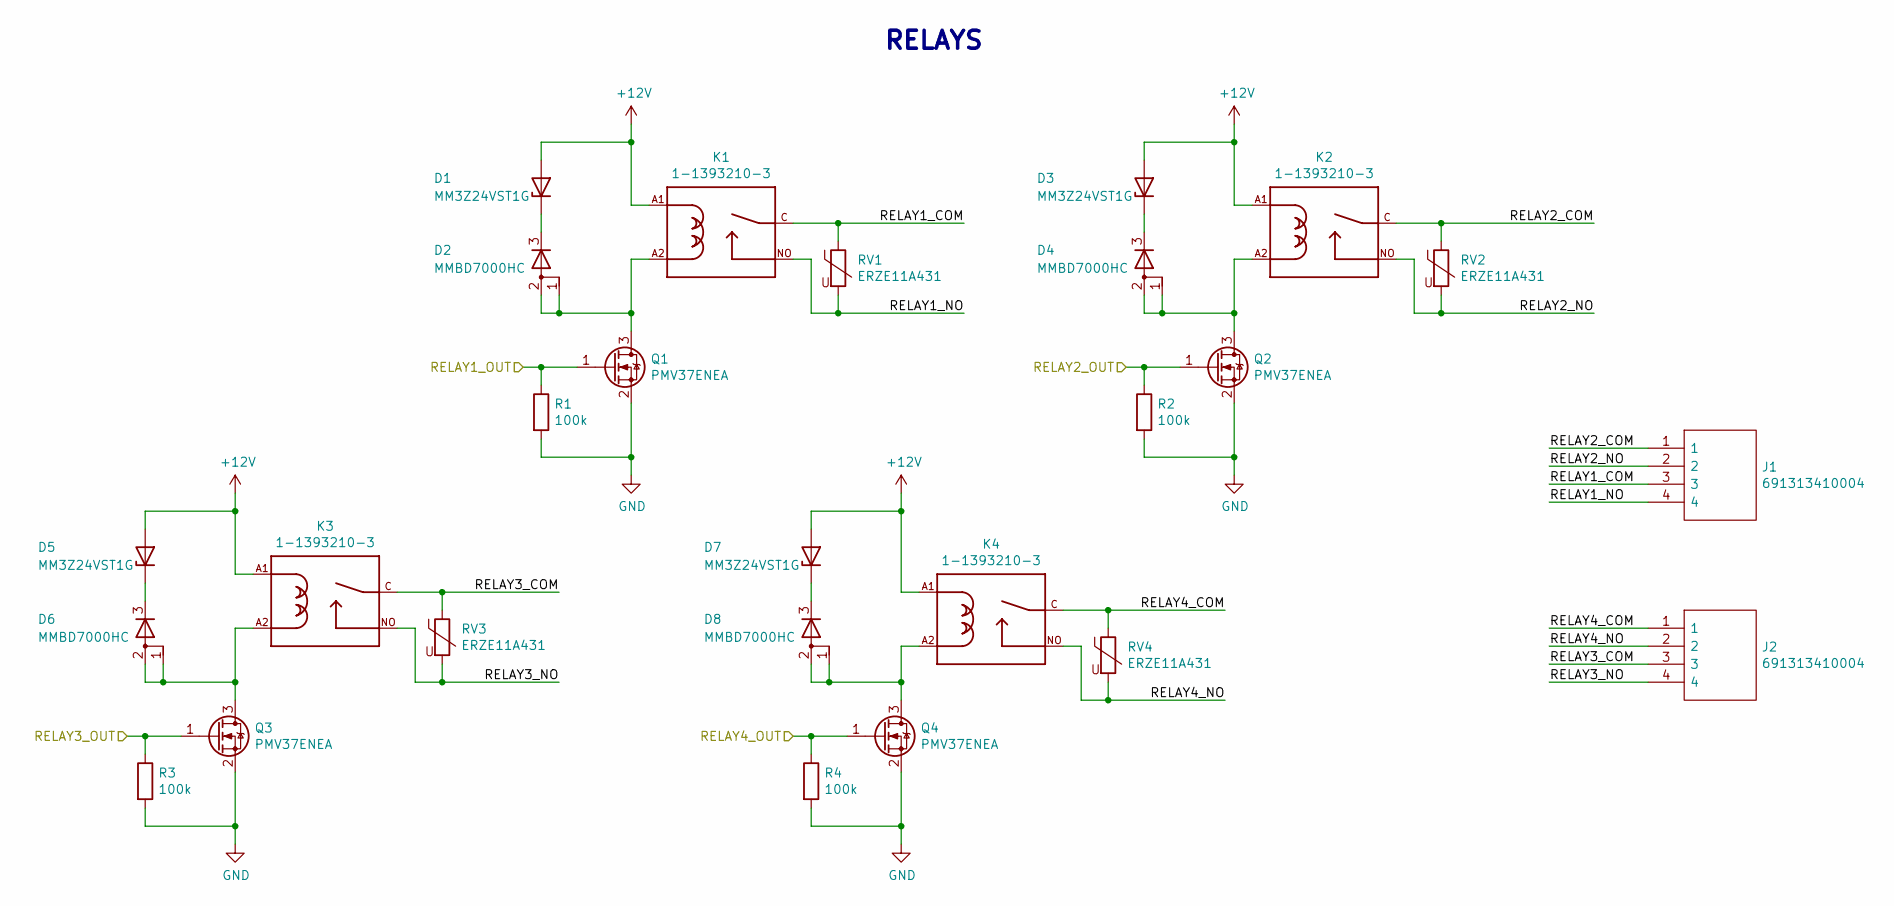
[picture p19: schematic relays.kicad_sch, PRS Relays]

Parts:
D1, D3, D5, D7: MM3Z24VST1G; D_SOD-323
D2, D4, D6, D8: MMBD7000HC; SOT-23_Handsoldering
J1, J2: 691313410004; Manufacturer_Part_Number 691313410004; Mouser Part Number 710-691313410004
K1, K2, K3, K4: 1-1393210-3; TE_1-1393210-3
Q1, Q2, Q3, Q4: PMV37ENEA; SOT-23_Handsoldering
R1, R2, R3, R4: 100k; R_0603_1608Metric_Pad0.98x0.95mm_HandSolder
RV1, RV2, RV3, RV4: ERZE11A431; RV_Disc_D12mm_W6.3mm_P7.5mm

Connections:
+12V: D1.2 (A), D3.2 (A), D5.2 (A), D7.2 (A), K1.A1, K2.A1, K3.A1, K4.A1; also elsewhere on the board
/Front Panel/RELAY1_OUT: Q1.1 (G), R1.1; also elsewhere on the board
/Front Panel/RELAY2_OUT: Q2.1 (G), R2.1; also elsewhere on the board
/Front Panel/RELAY3_OUT: Q3.1 (G), R3.1; also elsewhere on the board
/Front Panel/RELAY4_OUT: Q4.1 (G), R4.1; also elsewhere on the board
/Relays/RELAY1_COM: J1.3, K1.C, RV1.1
/Relays/RELAY1_NO: J1.4, K1.NO, RV1.2
/Relays/RELAY2_COM: J1.1, K2.C, RV2.1
/Relays/RELAY2_NO: J1.2, K2.NO, RV2.2
/Relays/RELAY3_COM: J2.3, K3.C, RV3.1
/Relays/RELAY3_NO: J2.4, K3.NO, RV3.2
/Relays/RELAY4_COM: J2.1, K4.C, RV4.1
/Relays/RELAY4_NO: J2.2, K4.NO, RV4.2
GND: Q1.2 (S), Q2.2 (S), Q3.2 (S), Q4.2 (S), R1.2, R2.2, R3.2, R4.2; also elsewhere on the board
unnamed: D1.1 (K), D2.3 (K)
unnamed: D2.1 (A), D2.2 (A), K1.A2, Q1.3 (D)
unnamed: D3.1 (K), D4.3 (K)
unnamed: D4.1 (A), D4.2 (A), K2.A2, Q2.3 (D)
unnamed: D5.1 (K), D6.3 (K)
unnamed: D6.1 (A), D6.2 (A), K3.A2, Q3.3 (D)
unnamed: D7.1 (K), D8.3 (K)
unnamed: D8.1 (A), D8.2 (A), K4.A2, Q4.3 (D)

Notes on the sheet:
RELAYS

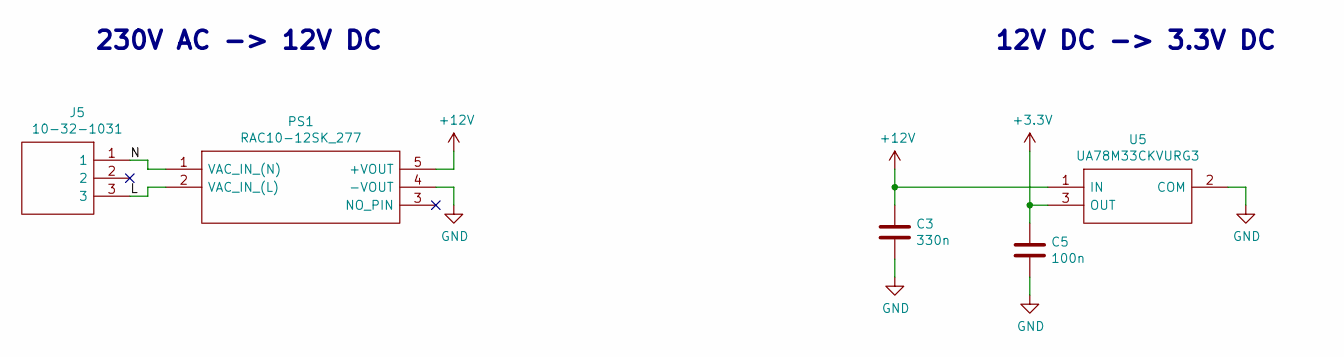
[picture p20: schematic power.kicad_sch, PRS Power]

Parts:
C3: 330n; C_0603_1608Metric_Pad1.08x0.95mm_HandSolder
C5: 100n; C_0603_1608Metric_Pad1.08x0.95mm_HandSolder
J5: 10-32-1031; SHDR3W114P0X508_1X3_1416X1140X1425P; Manufacturer_Part_Number 10-32-1031; Mouser Part Number 538-10-32-1031
PS1: RAC10-12SK_277; Manufacturer_Part_Number RAC10-12SK/277; Mouser Part Number 919-RAC10-12SK/277
U5: UA78M33CKVURG3; TPS7A6533QKVURQ1; Manufacturer_Part_Number UA78M33CKVURG3; Mouser Part Number 595-UA78M33CKVURG3

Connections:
+3V3: C5.1, U5.3 (OUT); also elsewhere on the board
+12V: C3.1, PS1.5 (+VOUT), U5.1 (IN); also elsewhere on the board
/Power/L: J5.3, PS1.2 (VAC_IN_(L))
/Power/N: J5.1, PS1.1 (VAC_IN_(N))
GND: C3.2, C5.2, PS1.4 (-VOUT), U5.2 (COM); also elsewhere on the board

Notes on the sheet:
12V DC -> 3.3V DC
230V AC -> 12V DC

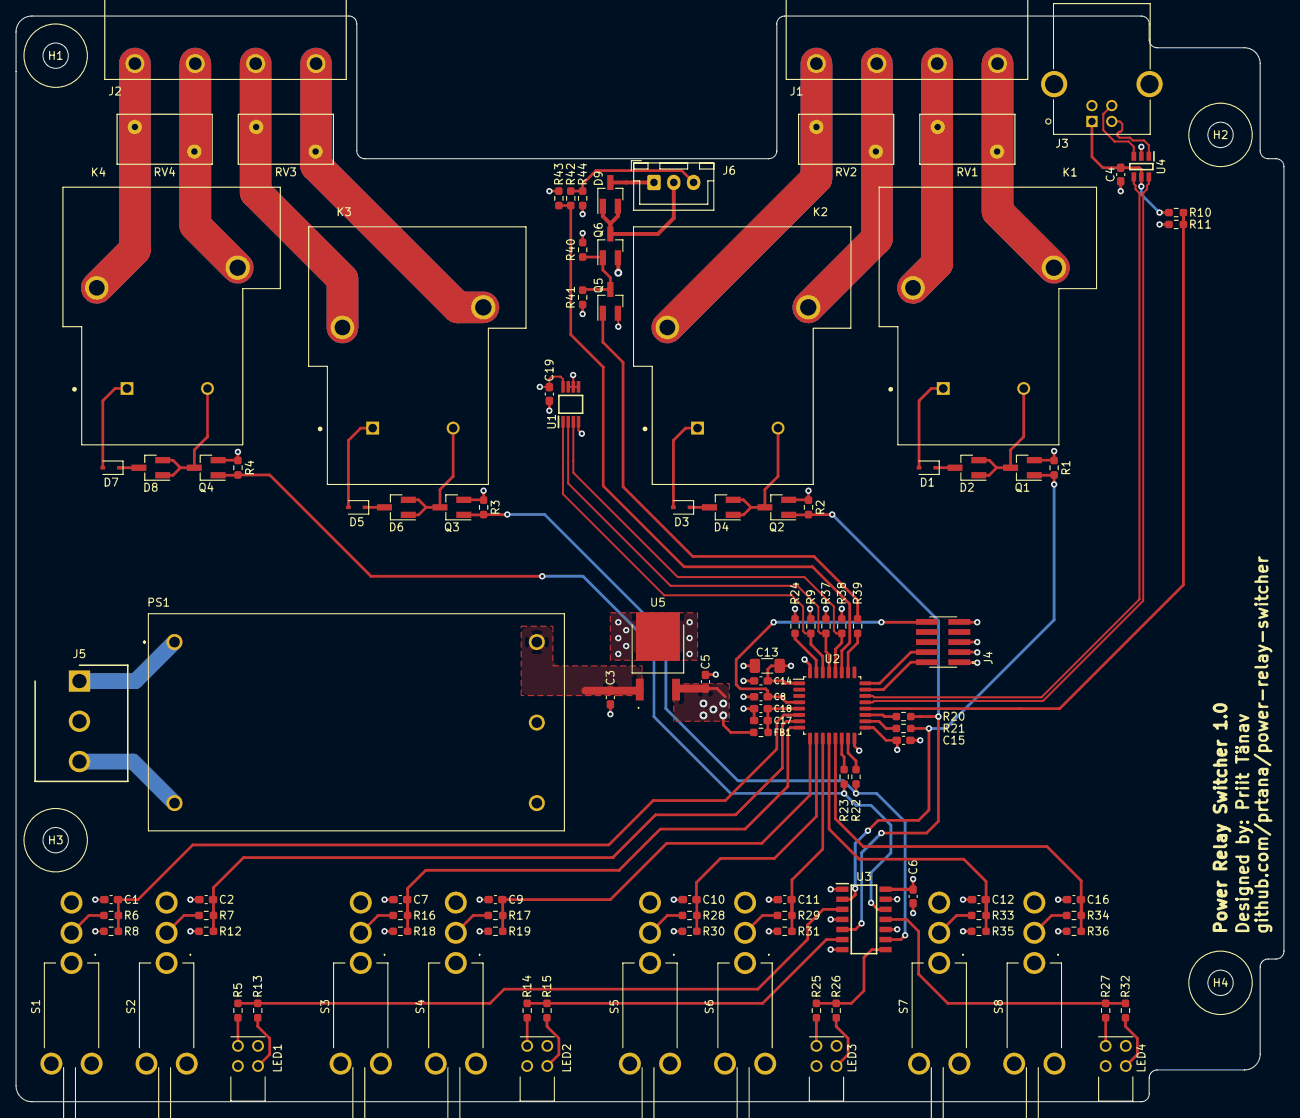
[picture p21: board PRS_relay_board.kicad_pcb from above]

Board: 4 copper layers, 160.0 x 137.0 mm, 115 parts (0 on the bottom side), 78 nets.

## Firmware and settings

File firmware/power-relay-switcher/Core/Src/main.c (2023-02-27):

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
/* Includes ------------------------------------------------------------------*/
#include "main.h"
#include "usb_device.h"

/* USER CODE BEGIN Includes */
#include "channels.h"
#include "usbd_cdc_if.h"
#include "STCN75.h"
#include "fan.h"
#include "scpi-def.h"
#include "scpi/scpi.h"
/* USER CODE END Includes */

I2C_HandleTypeDef hi2c1;

RTC_HandleTypeDef hrtc;

/* USER CODE BEGIN PV */
extern bool any_switch_toggled;
STCN75_Typedef temp_sensor;
FanTypedef fan;
scpi_t scpi_context;
extern SCPIIntermediateBufferTypedef scpi_intermediate_buffer;
/* USER CODE END PV */

void SystemClock_Config(void);
static void MX_GPIO_Init(void);
static void MX_I2C1_Init(void);
static void MX_RTC_Init(void);
/**
  * @brief  The application entry point.
  * @retval int
  */
int main(void)
{
  /* MCU Configuration--------------------------------------------------------*/

  /* Reset of all peripherals, Initializes the Flash interface and the Systick. */
  HAL_Init();

  /* Configure the system clock */
  SystemClock_Config();

  /* Initialize all configured peripherals */
  MX_GPIO_Init();
  MX_USB_DEVICE_Init();
  MX_I2C1_Init();
  MX_RTC_Init();
  /* USER CODE BEGIN 2 */
  SetRelaysPositions(true);
  STNC75_Initialize(&temp_sensor, &hi2c1);
  Fan_Initialize(&fan);
  SCPI_Initialize(&scpi_context);
  /* USER CODE END 2 */

  /* Infinite loop */
  /* USER CODE BEGIN WHILE */
  while (1)
  {
	  if (any_switch_toggled)
	  {
		  SetRelaysPositions(false);
		  any_switch_toggled = false;
	  }

	  if (scpi_intermediate_buffer.new_data_available)
	  {
		  scpi_intermediate_buffer.new_data_available = false;
		  SCPI_Input(&scpi_context, scpi_intermediate_buffer.buffer, scpi_intermediate_buffer.length);
	  }
    /* USER CODE END WHILE */

    /* USER CODE BEGIN 3 */
  }
  /* USER CODE END 3 */
}

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
/* USER CODE BEGIN 4 */
void HAL_RTCEx_WakeUpTimerEventCallback (RTC_HandleTypeDef *hrtc)
{
	ReadTemperature(&temp_sensor);
	if (temp_sensor.temp_C > temp_sensor.overlimit_temp_C)
	{
		Fan_SetState (&fan, FAN_RUNNING);
		return;
	}
	if (temp_sensor.temp_C < temp_sensor.hysteresis_temp_C)
	{
		Fan_SetState (&fan, FAN_STOPPED);
		return;
	}
}
/* USER CODE END 4 */
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


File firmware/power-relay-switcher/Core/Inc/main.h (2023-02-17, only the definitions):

#define RELAY_1_USB_MAN_Pin GPIO_PIN_0
#define RELAY_1_USB_MAN_GPIO_Port GPIOA
#define RELAY_1_USB_MAN_EXTI_IRQn EXTI0_1_IRQn
#define RELAY_1_IN_Pin GPIO_PIN_1
#define RELAY_1_IN_GPIO_Port GPIOA
#define RELAY_1_IN_EXTI_IRQn EXTI0_1_IRQn
#define RELAY_2_USB_MAN_Pin GPIO_PIN_2
#define RELAY_2_USB_MAN_GPIO_Port GPIOA
#define RELAY_2_USB_MAN_EXTI_IRQn EXTI2_3_IRQn
#define RELAY_2_IN_Pin GPIO_PIN_3
#define RELAY_2_IN_GPIO_Port GPIOA
#define RELAY_2_IN_EXTI_IRQn EXTI2_3_IRQn
#define RELAY_3_USB_MAN_Pin GPIO_PIN_4
#define RELAY_3_USB_MAN_GPIO_Port GPIOA
#define RELAY_3_USB_MAN_EXTI_IRQn EXTI4_15_IRQn
#define RELAY_3_IN_Pin GPIO_PIN_5
#define RELAY_3_IN_GPIO_Port GPIOA
#define RELAY_3_IN_EXTI_IRQn EXTI4_15_IRQn
#define RELAY_4_USB_MAN_Pin GPIO_PIN_6
#define RELAY_4_USB_MAN_GPIO_Port GPIOA
#define RELAY_4_USB_MAN_EXTI_IRQn EXTI4_15_IRQn
#define RELAY_4_IN_Pin GPIO_PIN_7
#define RELAY_4_IN_GPIO_Port GPIOA
#define RELAY_4_IN_EXTI_IRQn EXTI4_15_IRQn
#define RELAY_4_OUT_Pin GPIO_PIN_0
#define RELAY_4_OUT_GPIO_Port GPIOB
#define RELAY_3_OUT_Pin GPIO_PIN_1
#define RELAY_3_OUT_GPIO_Port GPIOB
#define RELAY_1_OUT_Pin GPIO_PIN_8
#define RELAY_1_OUT_GPIO_Port GPIOA
#define RELAY_2_OUT_Pin GPIO_PIN_9
#define RELAY_2_OUT_GPIO_Port GPIOA
#define FAN_CTRL_Pin GPIO_PIN_3
#define FAN_CTRL_GPIO_Port GPIOB
#define FAN_TACH_Pin GPIO_PIN_4
#define FAN_TACH_GPIO_Port GPIOB

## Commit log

2021-10-02 KiCad default project
    [PRS.kicad_pcb, PRS.sch]
2021-10-02 Add relays
    [PRS.kicad_pcb, PRS.sch]
2021-10-02 Add Reference Materials
2021-10-12 Touched up relay schematics
    [PRS_relay_board.sch]
2021-10-12 Set resistor descriptions
    [PRS_relay_board.sch]
2021-10-12 Add Fan connector
    [PRS_relay_board.kicad_pcb, PRS_relay_board.sch]
2021-10-12 Distributed schematic between sheets
    [Cooling.sch, MCU.sch, PRS_relay_board.sch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]
2021-10-12 Set component description
    [Cooling.sch, MCU.sch, front_panel.sch]
2021-10-12 Set component values
    [Cooling.sch]
2021-10-12 Add Temperature sensor datasheet
2021-10-12 Rename relay datasheet
2021-10-12 Remove PRS_front_panel as design is consolidated into single PCB
    [PRS_front_panel.kicad_pcb, PRS_front_panel.sch]
2021-10-12 Set zener diode PN
    [relays.sch]
2021-10-12 Replace MCU with a larger Flash equivalent
    [MCU.sch]
2021-10-13 Add BOM
    [PRS_relay_board.kicad_pcb]
2021-10-13 Change C13 footprint
    [MCU.sch, PRS_relay_board.kicad_pcb]
2021-10-13 Decreased LED resistor values
    [front_panel.sch]
2021-10-13 Fixed broken wire
    [front_panel.sch]
2021-10-15 Change C13 footprint to 1206
    [MCU.sch]
2021-10-16 Create PCB Layout
    [Cooling.sch, MCU.sch, PRS_relay_board.kicad_pcb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]
2022-01-12 Add PRS_front_panel KiCad project & Gerbers
    [PRS_front_panel.kicad_pcb, PRS_front_panel.sch, PRS_front_panel.step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]
2022-01-12 Add Gerbers
    [PRS_relay_board-B_Cu.gbl, PRS_relay_board-B_Mask.gbs, PRS_relay_board-B_Paste.gbp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]
2022-01-12 Add PRS_rear_panel KiCad project & Gerbers
    [PRS_rear_panel.kicad_pcb, PRS_rear_panel.sch, PRS_rear_panel.step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]
2022-01-15 Move to directory 3D
    [PRS_front_panel.step]
2022-01-15 Move to directory KiCad
    [Cooling.sch, MCU.sch, PRS_relay_board.kicad_pcb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]
2022-01-15 Move to KiCad/
    [PRS_rear_panel.kicad_pcb, PRS_rear_panel.sch]
2022-01-15 Add PDF schematic
2022-01-15 Add STM32 project
2022-01-29 Toggle relays via switch interrupts
2023-02-07 Upgrade to v6 KiCad
    [Cooling.kicad_sch, MCU.kicad_sch, PRS_relay_board.kicad_sch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]
2023-02-07 Remove KiCad v5 schematic files
    [Cooling.sch, MCU.sch, front_panel.sch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]
2023-02-08 Add KiCad v6 schematic files
    [Cooling.kicad_sch, MCU.kicad_sch, PRS_relay_board.kicad_sch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]
2023-02-08 Remove KiCad v5 project file
2023-02-08 Add KiCad v6 project file
2023-02-08 Remove symbol library table & footprint library table
2023-02-08 Update PRS_relay_board.kicad_pcb to KiCad v6
    [PRS_relay_board.kicad_pcb]
2023-02-08 Update PRS_front_panel to KiCad v6
    [PRS_front_panel.kicad_pcb, PRS_front_panel.kicad_sch, PRS_front_panel.sch]
2023-02-08 Update PRS_rear_panel to KiCad v6
    [PRS_rear_panel.kicad_pcb, PRS_rear_panel.kicad_sch, PRS_rear_panel.sch]
2023-02-14 Add STCN75 driver
2023-02-17 Set overlimit and hysteresis temperatures
2023-02-17 Add fan control
2023-02-19 Fix temperature checking
2023-02-20 Set fan resistor values
    [Cooling.kicad_sch, MCU.kicad_sch, PRS_relay_board.kicad_sch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]
2023-02-20 Fix 3d model paths
    [PRS_relay_board.kicad_pcb]
2023-02-20 Update BOM
2023-02-20 Add missing HAL drivers
2023-03-01 Add PCB 3D images
2023-03-03 Add STM32CubeIDE project files

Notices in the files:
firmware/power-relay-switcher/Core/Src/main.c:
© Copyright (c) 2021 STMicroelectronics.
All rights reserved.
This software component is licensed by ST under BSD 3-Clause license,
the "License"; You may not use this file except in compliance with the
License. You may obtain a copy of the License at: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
